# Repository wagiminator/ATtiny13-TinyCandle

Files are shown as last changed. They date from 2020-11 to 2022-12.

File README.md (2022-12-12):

# TinyCandle - Candle Simulation based on ATtiny13A
A simple tealight candle simulation based on the ATtiny13A.

- Design Files (EasyEDA): https://easyeda.com/wagiminator/attiny13-tinycandle

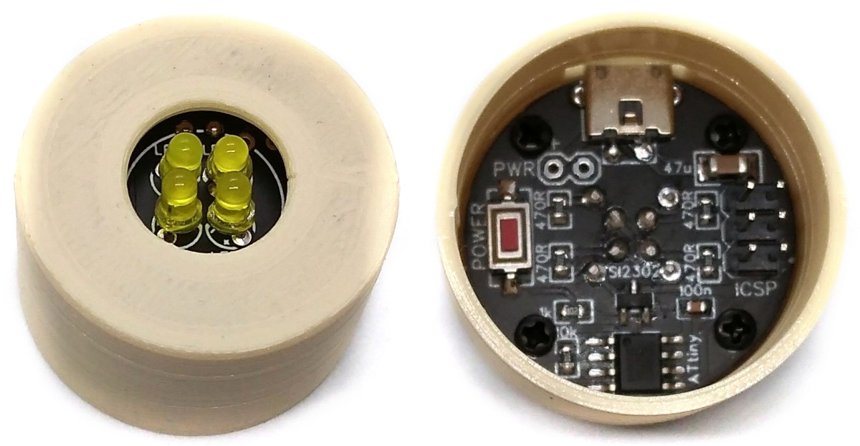
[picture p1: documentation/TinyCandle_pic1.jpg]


# Software
## Candle Simulation
The simulation code is based on the great work of [Mark Sherman](https://github.com/carangil/candle). With most LED candles, the random flickering is rather silly and lacks the spooky element of candlelight: shadows cast by the candle move because the flame is in motion. With TinyCandle, four LEDs are arranged in a square, their intensity forms a "center" of light balance that can be moved around smoothly.

This 'physics-based' candlelight has the following properties:
- The flame has a position and a velocity.
- If the position is not centered, the velocity will accelerate towards the center in proportion to the displacement (hooke's law of springs).
- The velocity has a very small damping value, which means that corrections towards the center always overshoot a bit (underdamped system).
- Random "pushes" into the center position of the light are performed to mimic random drafts.
- The strength of the drafts changes periodically (alternating periods of calm and windiness).

## Pseudo Random Number Generator
The implementation of the candle simulation requires random numbers for a realistic flickering of the candle. However, the usual libraries for generating random numbers require a relatively large amount of memory. Fortunately, Łukasz Podkalicki has developed a [lightweight random number generator](https://blog.podkalicki.com/attiny13-pseudo-random-numbers/) based on [Galois linear feedback shift register](https://en.wikipedia.org/wiki/Linear-feedback_shift_register#Galois_LFSRs) for the ATtiny13A, which is also used here, slightly adapted. When compiled, this function only requires **86 bytes of flash**.

```c
// Start state (any nonzero value will work)
uint16_t rn = 0xACE1;

// Pseudo random number generator
uint16_t prng(uint16_t maxvalue) {
  rn = (rn >> 0x01) ^ (-(rn & 0x01) & 0xB400);
  return(rn % maxvalue);
}
```

## Compiling and Uploading Firmware
### If using the Arduino IDE
- Make sure you have installed [MicroCore](https://github.com/MCUdude/MicroCore).
- Go to **Tools -> Board -> MicroCore** and select **ATtiny13**.
- Go to **Tools** and choose the following board options:
  - **Clock:**  1.2 MHz internal osc.
  - **BOD:**    disabled
  - **Timing:** Micros disabled
- Connect your programmer to your PC and to the ICSP header on the board.
- Go to **Tools -> Programmer** and select your ISP programmer (e.g. [USBasp](https://aliexpress.com/wholesale?SearchText=usbasp)).
- Go to **Tools -> Burn Bootloader** to burn the fuses.
- Open the TinyCandle sketch and click **Upload**.

### If using the precompiled hex-file
- Make sure you have installed [avrdude](https://learn.adafruit.com/usbtinyisp/avrdude).
- Connect your programmer to your PC and to the ICSP header on the board.
- Open a terminal.
- Navigate to the folder with the hex-file.
- Execute the following command (if necessary replace "usbasp" with the programmer you use):
  ```
  avrdude -c usbasp -p t13 -U lfuse:w:0x2a:m -U hfuse:w:0xff:m -U flash:w:tinycandle.hex
  ```

### If using the makefile (Linux/Mac)
- Make sure you have installed [avr-gcc toolchain and avrdude](http://maxembedded.com/2015/06/setting-up-avr-gcc-toolchain-on-linux-and-mac-os-x/).
- Connect your programmer to your PC and to the ICSP header on the board.
- Open a terminal.
- Navigate to the folder with the makefile and the Arduino sketch.
- Run `PROGRMR=usbasp make install` to compile, burn the fuses and upload the firmware (change PROGRMR accordingly).

# References, Links and Notes
1. [ATtiny13A Datasheet](http://ww1.microchip.com/downloads/en/DeviceDoc/doc8126.pdf)
2. [Candle Simulation Implementation by Mark Sherman](https://github.com/carangil/candle)
3. [Lightweight Random Number Generator by Łukasz Podkalicki](https://blog.podkalicki.com/attiny13-pseudo-random-numbers/)
4. [NeoCandle based on ATtiny25/45/85](https://github.com/wagiminator/ATtiny85-TinyCandle)

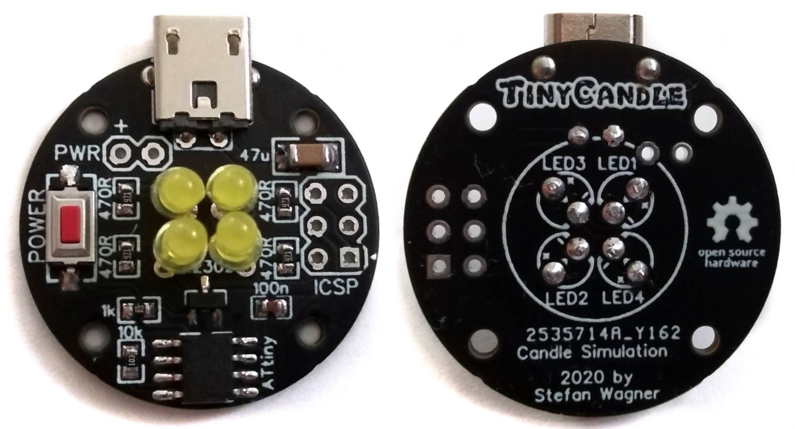
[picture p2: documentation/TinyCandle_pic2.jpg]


# License


This work is licensed under Creative Commons Attribution-ShareAlike 3.0 Unported License. 
(http://creativecommons.org/licenses/by-sa/3.0/)

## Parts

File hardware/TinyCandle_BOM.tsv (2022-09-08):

ID | Name | Designator | Footprint | Quantity | Manufacturer Part | Manufacturer | Supplier | Supplier Part | Price
1 | 100n | C1 | 603 | 1 | CC0603KRX7R9BB104 | YAGEO | LCSC | C14663 | 0.0034
2 | 47u | C2 | 1206 | 1 | 1206F476M160NT | FH | LCSC | C30300 | 143
3 | ICSP-6 | ICSP | ICSP-6 | 1 | MTP125-1203S1 | MINTRON | LCSC | C358692 | 22
4 | LED-YELLOW | LED1,LED2,LED3,LED4 | LED-3MM/2.54 | 4 | 204-10UYD/S530-A3-L | EVERLIGHT | LCSC | C85160 | 0.0334
5 | 3x6x2.5 | POWER | KEY-3.0*6.0 | 1 | 3x6x2.5Red head high temperature | ReliaPro | LCSC | C46491 | 0.0227
6 | Header | PWR | HEADER_2X1 | 1 | 826629-2 | TE Connectivity | LCSC | C86471 | 0.2091
7 | SI2302 | Q2 | SOT-23_L2.9-W1.3-P0.95-LS2.4-BR | 1 | SI2302 | Bourne Semicon (Shenzhen) | LCSC | C344009 | 35
8 | 10k | R1 | 603 | 1 | 0603WAF1002T5E | UniOhm | LCSC | C25804 | 1
9 | 220R | R2,R3,R4,R5 | 603 | 4 | 0603WAF2200T5E | UniOhm | LCSC | C22962 | 0.0012
10 | 1k | R6 | 603 | 1 | 0603WAF1001T5E | UniOhm | LCSC | C21190 | 1
11 | ATTINY13A-SSU | U1 | SOP-8_150MIL | 1 | ATTINY13A-SSU | MICROCHIP | LCSC | C14075 | 0.7416
12 | USB PWR Connector | USB | USB PWR CONNECTOR | 1 | KH-MICRO-SMT.J-2P | Shenzhen Kinghelm Elec | LCSC | C2688799 | 0.0549

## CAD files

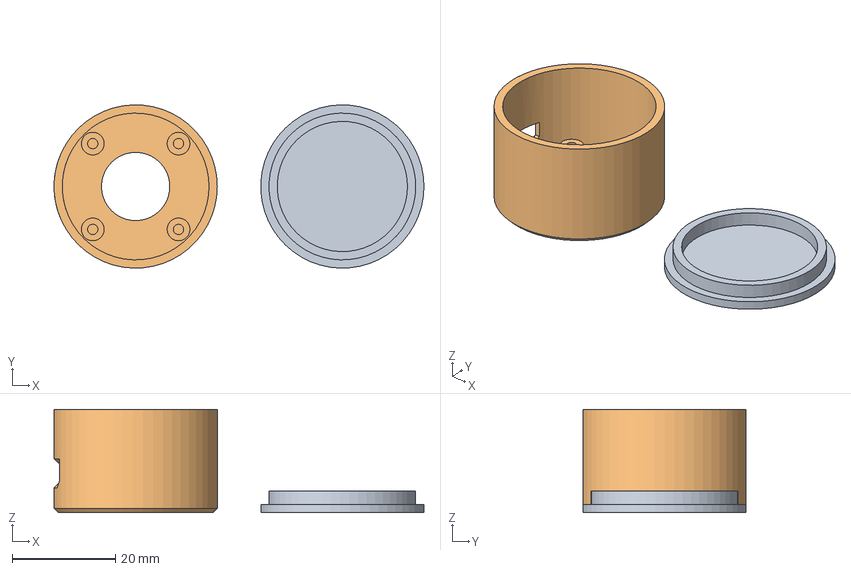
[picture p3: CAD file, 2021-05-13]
3dprint/TinyCandle_case.fcstd
71.6 x 31.6 x 20.0 mm
Cap
Case

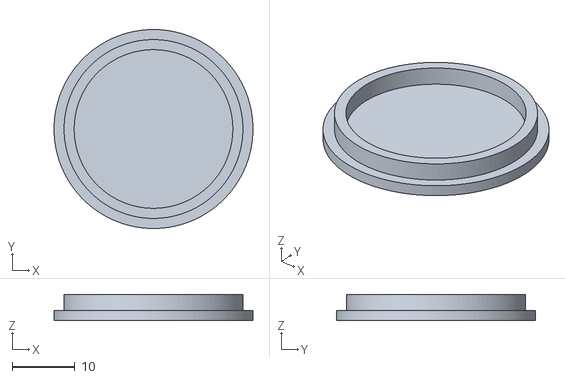
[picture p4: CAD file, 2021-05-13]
3dprint/TinyCandle_cap.stl
31.6 x 31.6 x 4.20

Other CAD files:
3dprint/TinyCandle_case.stl

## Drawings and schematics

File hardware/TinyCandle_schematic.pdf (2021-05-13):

## Microcontroller

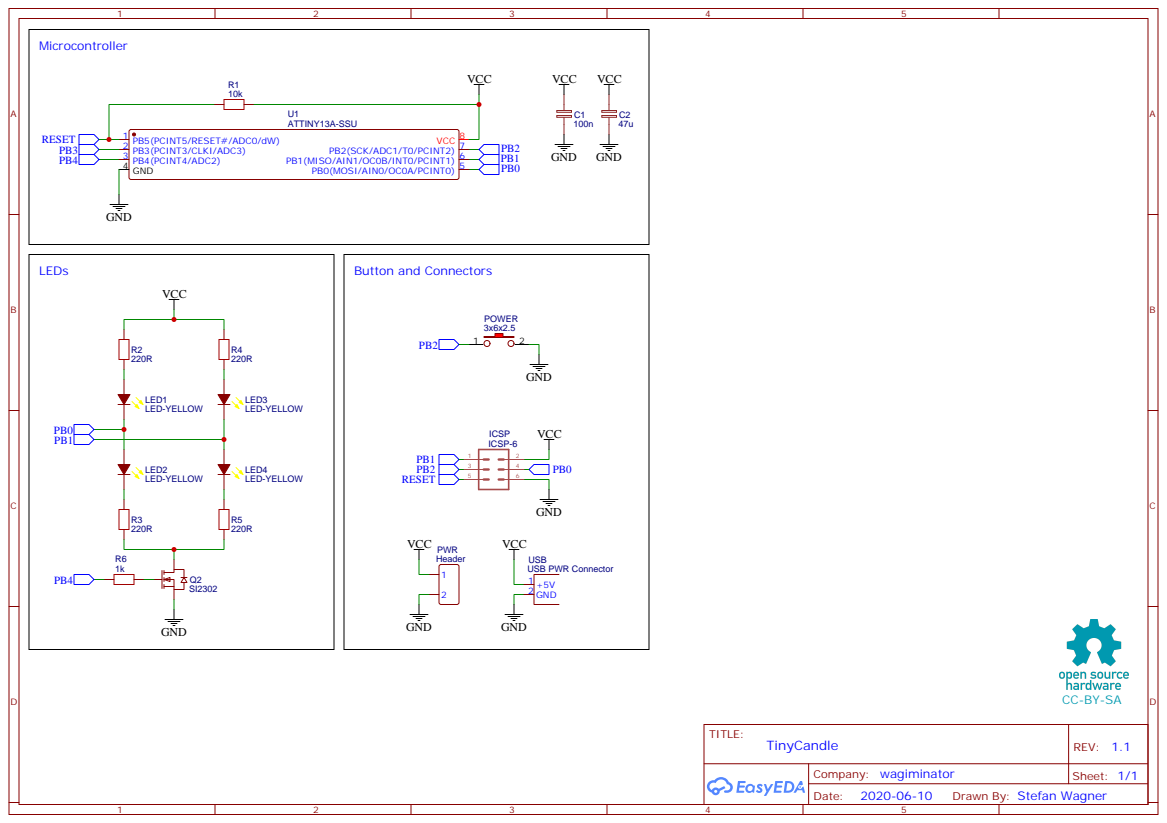
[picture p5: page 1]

Drawn By: Stefan Wagner

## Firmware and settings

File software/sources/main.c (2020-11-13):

// TinyCandle - ATtiny13A
//
// Tealight candle simulation for ATtiny13A.
// 
// The simulation code is based on the great work of Mark Sherman
// (https://github.com/carangil/candle).
//
// The lightweight pseudo random number generator based on 
// Galois linear feedback shift register is taken from Łukasz Podkalicki
// (https://blog.podkalicki.com/attiny13-pseudo-random-numbers/).
//
//
//                          +-\/-+
//        --- A0 (D5) PB5  1|    |8  Vcc
//        --- A3 (D3) PB3  2|    |7  PB2 (D2) A1 --- Button
// MOSFET --- A2 (D4) PB4  3|    |6  PB1 (D1) ------ LED3/4 PWM
//                    GND  4|    |5  PB0 (D0) ------ LED1/2 PWM
//                          +----+    
//
// Controller:  ATtiny13A
// Clockspeed:  1.2 MHz internal
//
// 2020 by Stefan Wagner 
// Project Files (EasyEDA): https://easyeda.com/wagiminator
// Project Files (Github):  https://github.com/wagiminator
// License: http://creativecommons.org/licenses/by-sa/3.0/


// less delay accuracy saves 16 bytes flash
#define __DELAY_BACKWARD_COMPATIBLE__ 1

// libraries
#include <avr/io.h>
#include <avr/sleep.h>
#include <avr/interrupt.h>
#include <util/delay.h>

// pin definitions
#define LED0          PB0
#define LED1          PB1
#define BUTTON        PB2
#define UNUSEDPIN     PB3
#define MOSFET        PB4

// candle simulation parameters
#define MINUNCALM     (20*256)
#define MAXUNCALM     (120*256)
#define UNCALMINC     20
#define MAXDEV        100
#define CANDLEDELAY   25

// some variables for the candle simulation
int16_t centerx   = MAXDEV;
int16_t centery   = MAXDEV/2;
int16_t xvel      = 0;
int16_t yvel      = 0;
uint16_t uncalm   = MINUNCALM;
int16_t uncalmdir = UNCALMINC;
uint8_t cnt       = 0;

// some variables for the random generator
uint16_t rn;

// pseudo random number generator
uint16_t prng(uint16_t maxvalue) {
  rn = (rn >> 0x01U) ^ (-(rn & 0x01U) & 0xB400U);
  return( (uint32_t)(maxvalue * rn) >> 16 );
}

// candle simulation
void updateCandle(void) {
  int movx = 0;
  int movy = 0;
   
  // random poke, intensity determined by uncalm value (0 is perfectly calm)
  movx = prng(uncalm >> 8) - (uncalm >> 9);
  movy = prng(uncalm >> 8) - (uncalm >> 9);
  
  // if reach most calm value, start moving towards uncalm
  if (uncalm < MINUNCALM) uncalmdir = UNCALMINC;
  
  // if reach most uncalm value, start going towards calm
  if (uncalm > MAXUNCALM) uncalmdir = -UNCALMINC;
  uncalm += uncalmdir;

  // move center of flame by the current velocity
  centerx += movx + (xvel >> 2);
  centery += movy + (yvel >> 2); 
  
  // range limits
  if (centerx < -MAXDEV) centerx = -MAXDEV;
  if (centerx >  MAXDEV) centerx =  MAXDEV;
  if (centery < -MAXDEV) centery = -MAXDEV; 
  if (centery >  MAXDEV) centery =  MAXDEV;

  // counter
  cnt++;
  if (! (cnt & 3)) {
    //attenuate velocity 1/4 clicks 
    xvel = (xvel * 999) / 1000;
    yvel = (yvel * 999) / 1000;
  }

  // apply acceleration towards center, proportional to distance from center (spring motion; hooke's law)
  xvel -= centerx;
  yvel -= centery;

  // set LEDs
  OCR0A = 155 + centerx;
  OCR0B = 155 + centery;
}

// main function
int main(void) {
  // PWM setup
  TCCR0A = (1<<COM0A1) | (1<<COM0B1)    // clear OC0A/OC0B on compare match, set at TOP
         | (1<<WGM01)  | (1<<WGM00);    // fast PWM 0x00 - 0xff
  TCCR0B = (1<<CS01);                   // set prescaler div8

  // setup pins
  DDRB   = (1<<LED0) | (1<<LED1)        // LED pins as output
         | (1<<MOSFET)                  // MOSFET pin as output
         | (1<<UNUSEDPIN);              // unused pin to output low to save power
  PORTB  = (1<<BUTTON) | (1<<MOSFET);   // pullup for button + MOSFET on

  // setup pin change interrupt
  GIMSK = (1<<PCIE);                    // turn on pin change interrupts
  PCMSK = (1<<BUTTON);                  // pin change interrupt on button pin
  sei();                                // enable global interrupts

  // disable unused peripherals to save power
  ADCSRA = 0;                           // disable ADC
  ACSR   = (1<<ACD);                    // disable analog comperator
  PRR    = (1<<PRADC);                  // shut down ADC
  set_sleep_mode (SLEEP_MODE_PWR_DOWN); // set sleep mode to power down

  // main loop
  while(1) {
    updateCandle();                     // candle simulation
    if (~PINB & (1<<BUTTON)) {          // if button is pressed
      DDRB  &= ~((1<<LED0) | (1<<LED1));// LED pins as input (PWM off)
      PORTB &= ~(1<<MOSFET);            // switch off MOSFET
      _delay_ms(10);                    // debounce button
      while (~PINB & (1<<BUTTON));      // wait for button released
      _delay_ms(10);                    // debounce button
      sleep_mode();                     // sleep until button pressed
      DDRB  |= (1<<LED0) | (1<<LED1);   // LED pins as output (PWM on)
      PORTB |= (1<<MOSFET);             // switch on MOSFET
      _delay_ms(10);                    // debounce button
      while (~PINB & (1<<BUTTON));      // wait for button released
    }  
  _delay_ms(CANDLEDELAY);               // delay
  }
}

// pin change interrupt service routine
EMPTY_INTERRUPT (PCINT0_vect);          // nothing to be done here, just wake up from sleep

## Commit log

2020-09-20 Update files
    [TinyCandle_BOM.csv]
2022-09-08 Update BOM
    [TinyCandle_BOM.tsv]
